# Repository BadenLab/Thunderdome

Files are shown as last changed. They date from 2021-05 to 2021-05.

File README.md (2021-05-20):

<p align="right">
<h1 align="center">Zebrafish Thunderdome</h1></p>
<h3 align="center">An open source and versatile spatio-chromatic stimulation system for behavioural experiments</h4>
<p align="center"><h6 align="right">by M.J.Y. Zimmermann, A.M. Chagas, G. Kafetzis & T. Baden</h6></p>

<br>

This project is licensed under the [GNU General Public License v3.0](https://github.com/BadenLab/LED-Zappelin/blob/master/LICENSE)<br>
The hardware is licensed under the [CERN OHL v1.2](https://github.com/BadenLab/LED-Zappelin/blob/master/PCB/LICENSE)

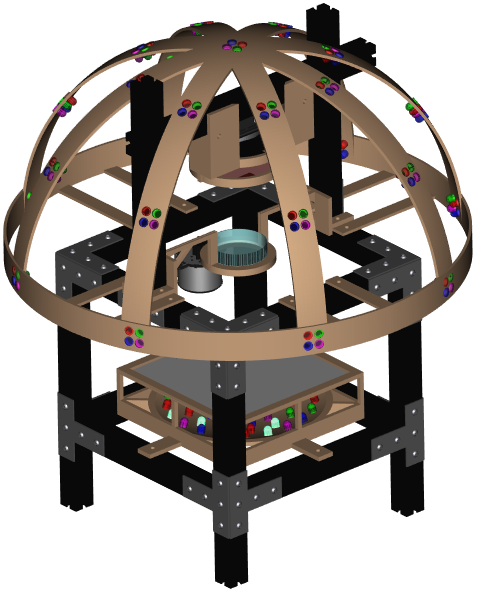
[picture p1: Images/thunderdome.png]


***

<h4 align="justify"> This project aims to investigate the larval zebrafish behavioural responses to spatio-chromatic stimulation in a free-swimming environment. The "Thunderdome"© is a stimulation system designed to experiment on the tetra-chromatic larval zebrafish. It is therefore designed around 4 set of LEDs (each LED matching the zebrafish' opsins peak absorption <a href="https://github.com/MaxZimmer/Zebra-Thunderdome/blob/main/References/Zimmermann%202018.pdf">Zimmermann et al. 2018</a> & <a href="https://github.com/MaxZimmer/Zebra-Thunderdome/blob/main/References/Zimmermann%202020.pdf">Zimmermann et al. 2020</a>, organised in 8 cardinal directions and 4 azimuths. Using machine-learning algorithms, fish motor responses (body direction, eyes orientation, tail kinetics, etc.) are identified and compared to well-known behavioural catalogs <a href="">ref</a> . The purpose of this project is to identify behavioural responses to specific spatio-chromatic stimulation which were/are studied in early visual system under two photon microscopy <a href="">ref,ref,ref</a></h4>

***

- [An open and versatile LED controler](#Introduction)
- [A semi-automated behavioural tracking](#Behaviour-tracking)
- [A detailed assembly and instruction manual](https://github.com/BadenLab/LED-Zappelin/blob/master/)
- [Required software](#Required_software)
- [Repository Structure](#Repository-Structure)

***

## Introduction

bonsai

***
## Behaviour tracking

<p align="justify">
For tracking the larval zebrafish movements, we are considering two different approaches:

- <a href="https://github.com/DeepLabCut/DeepLabCut">DeepLabCut</a>, a toolbox for markerless pose estimation based on transfer learning with deep neural networks that achieves excellent results with minimal training data <a href="https://github.com/MaxZimmer/Zebra-Thunderdome/blob/main/References/Mathis%202018.pdf">Mathis et al. 2018</a>, <a href="https://github.com/MaxZimmer/Zebra-Thunderdome/blob/main/References/Nath&Mathis%202019.pdf">Nath & Mathis 2019</a>.

- <a href="https://github.com/ncguilbeault/BonZeb">BonZeb</a>, a Bonsai library for high-resolution zebrafish behavioural tracking and analysis <a href="https://github.com/MaxZimmer/Zebra-Thunderdome/blob/main/References/Guilbeault%202019.pdf">Guilbeault 2019</a>  
</p>

***

## Required software

***

## Repository structure

```
├───3D Designs                                Contains printed parts for the stimulator
|   ├───FreeCad renderings                      - Printing files
|   ├───STL files                               - Printing files
|   └───SCAD files                              - SCAD files to be modified if need be
|
├───Arduino Code                              Stimulator Code
|   ├───Stimulator Code                       - Adaptable C+ code for running the stimulator
|   └───LED driver library                     - Library to run the TLC 5947
|
├───Bill of Materials                         List of necessary components and retailer suggestions
|
├───Bonsai code                               Bonsai pipeline for running the stimulation and export data
|
├───Datasheets                                - Contains all technical sheet for:
|   ├───Stimulator                            - ...micro-controller and LED driver
|   └───Spectrometer                          - ...device used for calibration
|
├───Images                                    Image repository
|
├───Instruction Manual                        Detailed manual to assemble and calibrate the stimulator
|   └───Stimulator Calibration                - Contains calibration recordings and the adaptable jupyter notebook script to calibrate the stimulator
|
├───PCB                                       KiCad and Gerber files to modify and generate PCB
|
└───References                                Publication used to design and conceive this model

```

***

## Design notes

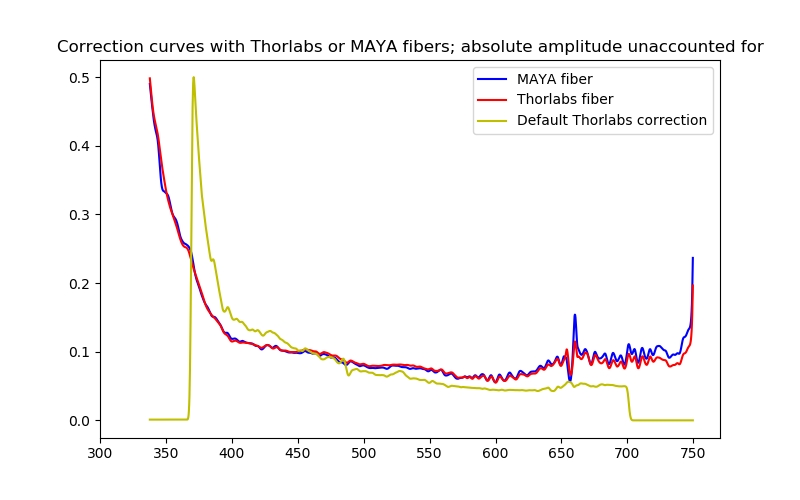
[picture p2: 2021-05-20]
Instruction Manual/Stimulator Calibration/Spectrometer_Recording/Spectrometer Correction Curves/Correction_curves.png

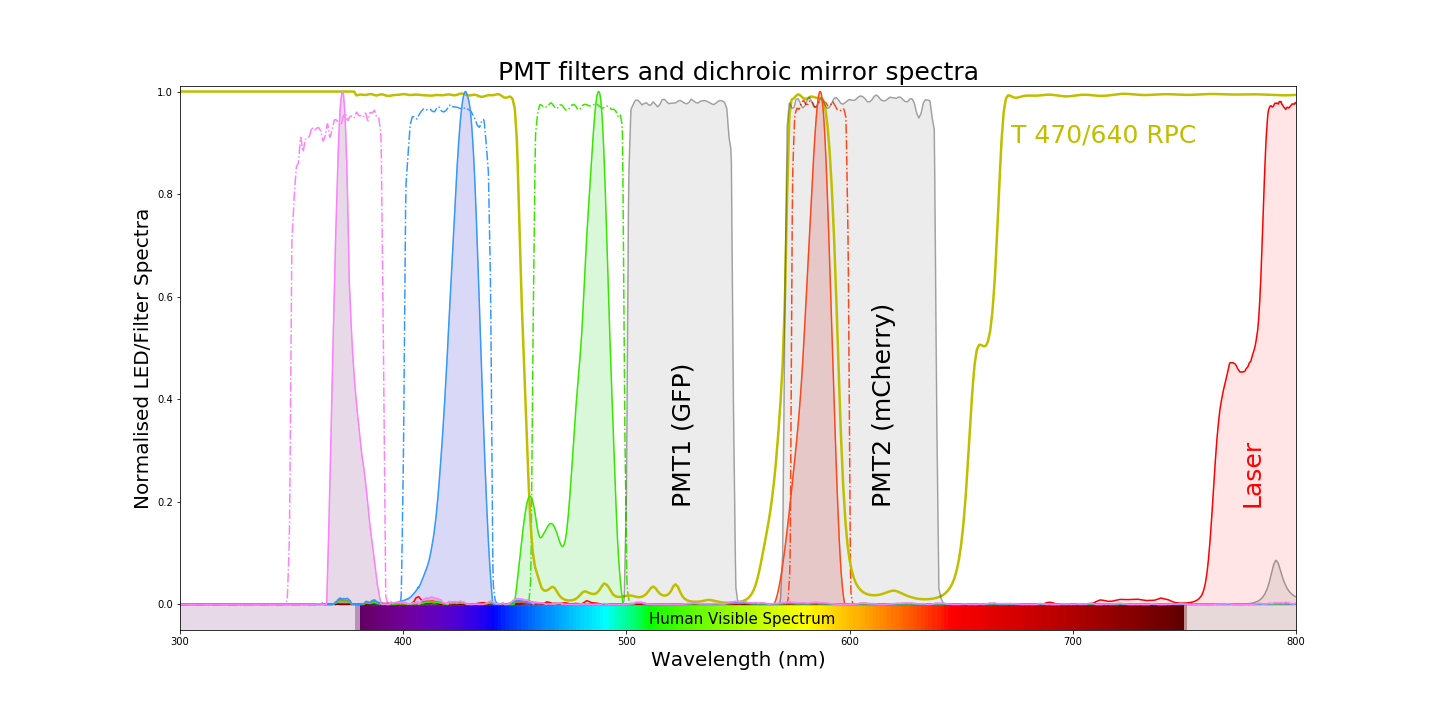
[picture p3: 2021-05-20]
Instruction Manual/Stimulator Calibration/Calibration_Figures/LED-PMT_Spectra.png

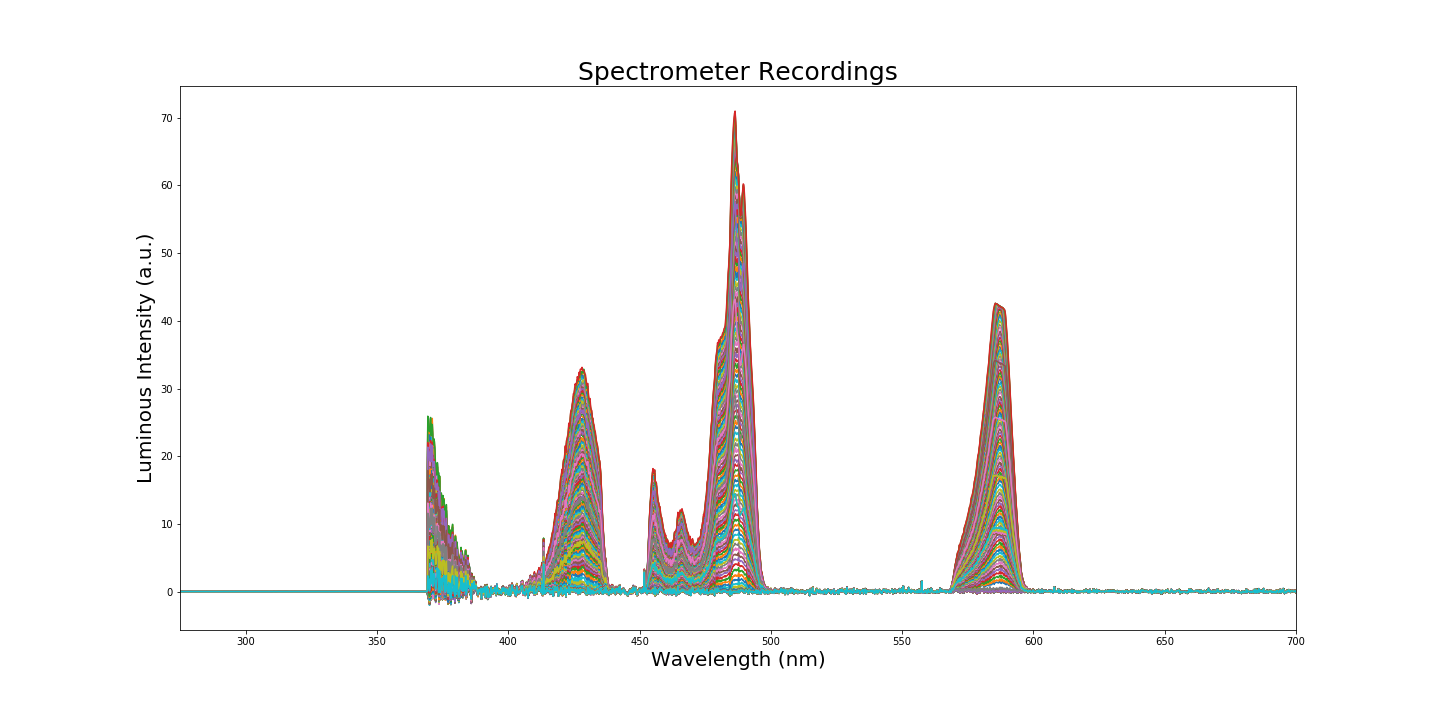
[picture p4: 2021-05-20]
Instruction Manual/Stimulator Calibration/Calibration_Figures/Spectrometer Recordings.png

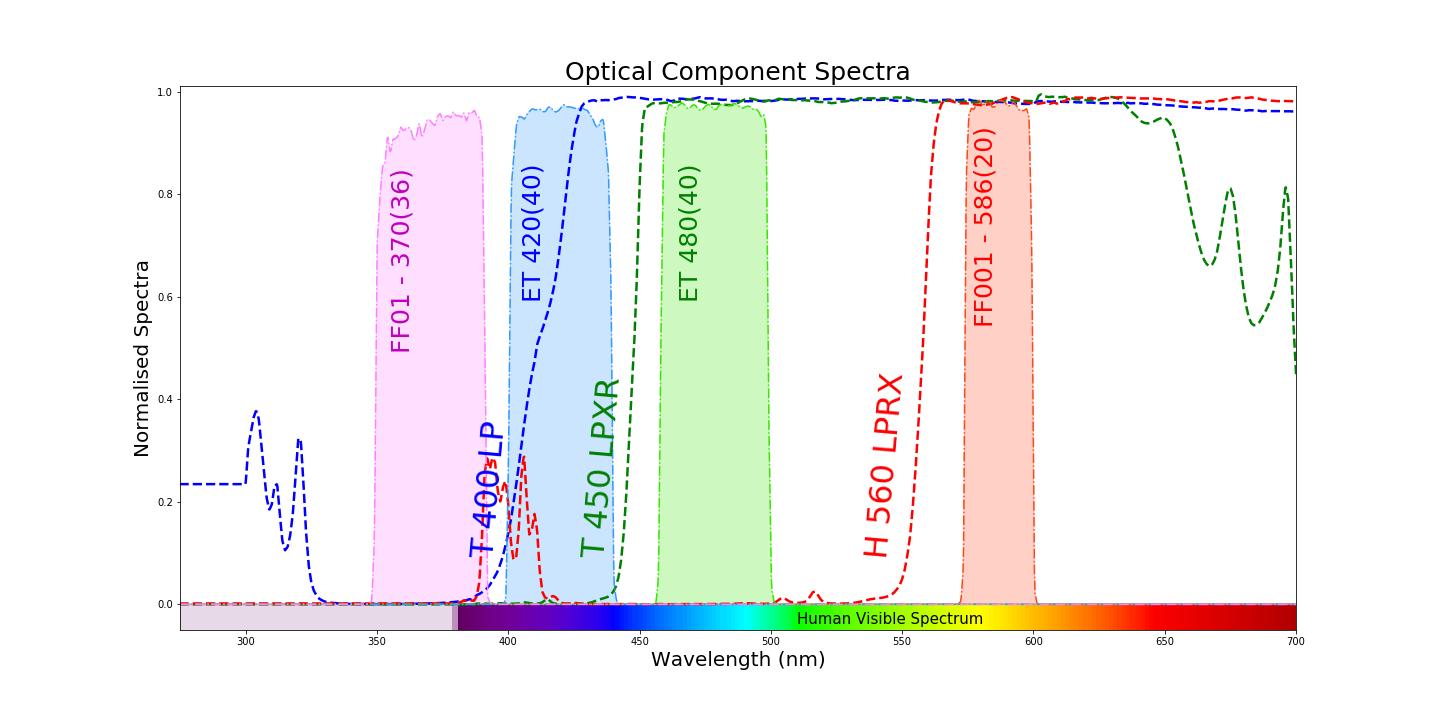
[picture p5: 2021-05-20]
Instruction Manual/Stimulator Calibration/Calibration_Figures/Optics_Spectra.png

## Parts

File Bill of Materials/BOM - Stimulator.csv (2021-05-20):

Name | Manufacturer | Order ID | Retailer | Quantity | Observation 1 | Observation 2 | Suggested URL | Cost
Adafruit Huzzah32 - ESP32 Feather | Adafruit | 3405 | Adafruit | 1 | Development Board | Easier to order it with header pins soldered | https://www.adafruit.com/product/3405 | £17
Adafruit TLC5947 | Adafruit | 1429 | Adafruit | 1 | LED Driver |  | https://www.adafruit.com/product/1429 | £12
BNC coaxial connectors | TE Connectivity | 1-1337542-0 | Farnell | 2 | Electronics | Right angle jacks, 50ohm | https://uk.farnell.com/greenpar-te-connectivity/1-1337542-0/rf-coaxial-bnc-right-angle-jack/dp/1020954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 | £3.70
2 way JST Female Connector Housing | RS Online | 820-1611 | JST | 8 | Electronics |  | https://uk.rs-online.com/web/p/pcb-connector-housings/8201611/ | £3.80
3 way JST Female Connector Housing | RS Online | 820-1614 | JST | 1 | Electronics |  | https://uk.rs-online.com/web/p/pcb-connector-housings/8201614/ | £1.90
4 way JST Female Connector Housing | RS Online | 820-1618 | JST | 2 | Electronics |  | https://uk.rs-online.com/web/p/pcb-connector-housings/8201618/ | £1.90
2 way JST PCB header | RS Online | 820-1554 | JST | 8 | Electronics |  | https://uk.rs-online.com/web/p/pcb-headers/8201554/ | £3.80
3 way JST PCB header | RS Online | 820-1557 | JST | 1 | Electronics |  | https://uk.rs-online.com/web/p/pcb-headers/8201557/ | £1.90
4 way JST PCB header | RS Online | 820-1551 | JST | 2 | Electronics |  | https://uk.rs-online.com/web/p/pcb-headers/8201551/ | £1.90
JST Crimp Connector Wire | RS Online | 01SHXSXH-26L 150 | RS | 15 | Electronics |  | https://uk.rs-online.com/web/p/products/8201548/ | £10.00
3 mm LED | Digikey | 350-1557-ND | Digikey | 4 | Electronics | 3mm round, tht | https://www.digikey.com/product-detail/en/dialight/5219210F/350-1557-ND/808955 | £2
Mount for 3 mm LED | Digikey | 67-1330-ND | Digikey | 4 | Electronics | 3mm panel mount | https://www.digikey.com/products/en?keywords=67-1330-ND | £1
Mount for 5 mm LED | Digikey | 67-1332-ND | Digikey | 4 | Electronics | 5mm panel mount | https://www.digikey.com/product-detail/en/lumex-opto-components-inc/SSH-LX5091/67-1332-ND/144810 | £1
Rocker LED switch |  |  | Ebay | 1 | Electronics | Round Switch / 3 pins | https://www.ebay.co.uk/p/Blue-On-off-Lighted-LED-Round-Rocker-Switch-Car-Dashboard-Dash-SPST-12v/1942302409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 | £2.50
220 Ohms Resitor | RS Online | 707-7612 | RS | 1 | Electronics | Through hole | https://uk.rs-online.com/web/p/through-hole-fixed-resistors/7077612/ | £1.16
470 Ohms Resitor | RS Online | 707-7647 | RS | 1 | Electronics | Through hole | https://uk.rs-online.com/web/p/through-hole-fixed-resistors/7077647/ | £1.16
10 kOhms Trimmer Potentiometer | TT Electronics | 89PR10KLF | Farnell | 4 | Electronics | Through Hole | https://uk.farnell.com/bi-technologies-tt-electronics/89pr10klf/trimmer-resistor/dp/1653213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 | £5.95
PCB socket | Samtec | SSW-116-02-G-S | RS | 6 | Electronics | 1 row, 15 pin | https://uk.rs-online.com/web/p/pcb-sockets/7655795/ | £3
2.1 mm right angle DC socket | RS Online | 884-0957 | RS | 1 | Electronics | 2.1 mm right angle | https://uk.rs-online.com/web/p/dc-power-sockets/8840957/ | £1
distinc colour wires | RS Online | 331-862 | RS | 100 cm | Electronics | 20 AWG | https://uk.rs-online.com/web/p/hookup-equipment-wire/0331862/ | £5
Cable shrink | RS Online | 170-6377 | RS | 20 cm | Electronics | Shrunk diameter 1.2 mm | https://uk.rs-online.com/web/p/heat-shrink-cold-shrink-sleeves/1706377/ | £1.58
M3 x 10mm screw | RS Online | 660-4636 | RS | 4 | Mechanical | M3 x 10 Hex socket cap | https://uk.rs-online.com/web/p/socket-screws/6604636/ | £4
M3 nut | RS Online | 122-4400 | RS | 4 | Mechanical | M3 nuts | https://uk.rs-online.com/web/p/hex-nuts/1224400/ | £4
M4 x 50mm Hex Socket Cap Screws | RS Online | 304-4592 | RS | 4 | Mechanical | M4 x 50 | https://uk.rs-online.com/web/p/socket-screws/3044592/ | £4
M4 nut | RS Online | 189-579 | RS | 4 | Mechanical | M4 nuts | https://uk.rs-online.com/web/p/hex-nuts/0189579/ | £4
 |  |  |  |  |  |  |  | £101

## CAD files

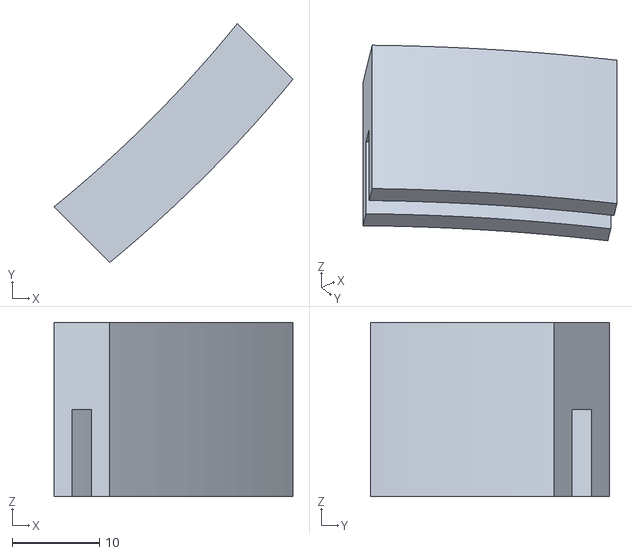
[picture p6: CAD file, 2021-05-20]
3D design/STL files/Dome_links.stl
27.5 x 27.5 x 20.0

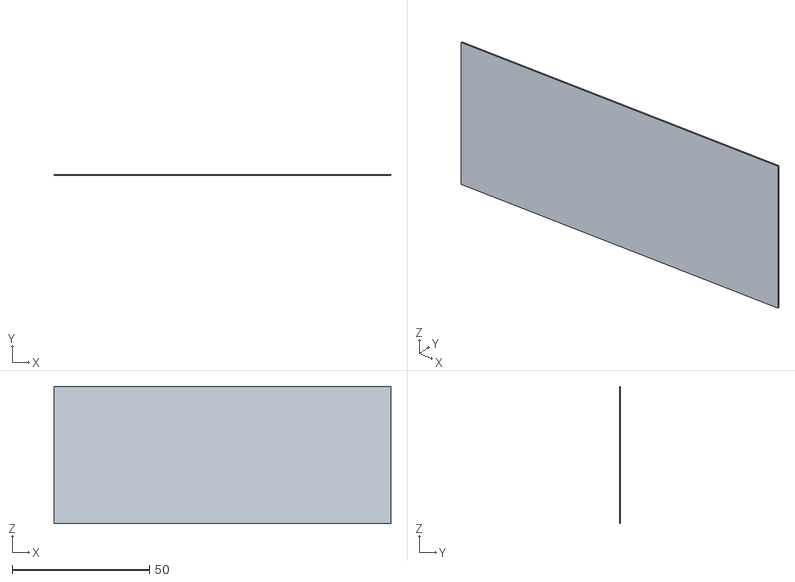
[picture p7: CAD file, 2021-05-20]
3D design/STL files/Dish_Separator.stl
122.8 x 0.5 x 50.0

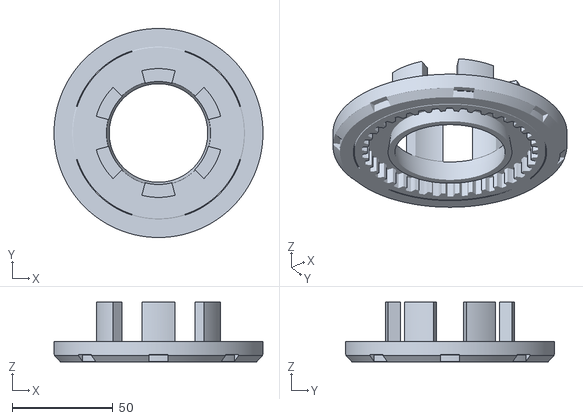
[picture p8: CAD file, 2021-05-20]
3D design/STL files/OKR_6.stl
103.5 x 103.5 x 29.5

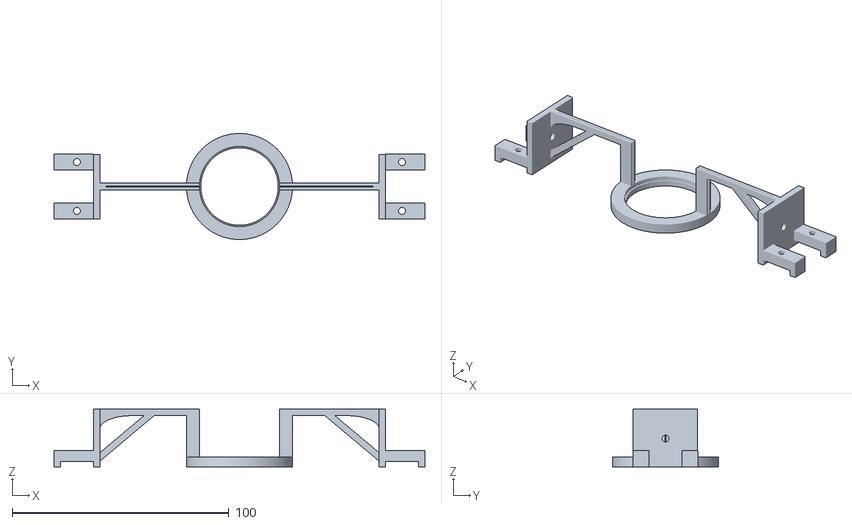
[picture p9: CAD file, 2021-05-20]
3D design/STL files/Dish_Holder.stl
171.2 x 49.0 x 26.7

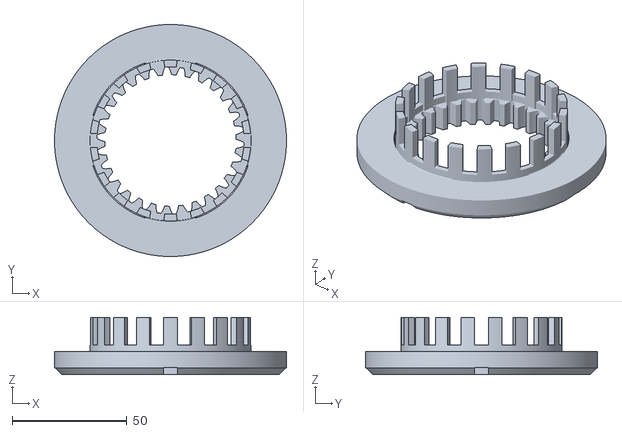
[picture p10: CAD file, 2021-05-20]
3D design/STL files/OKR_18.stl
101.0 x 101.0 x 25.0

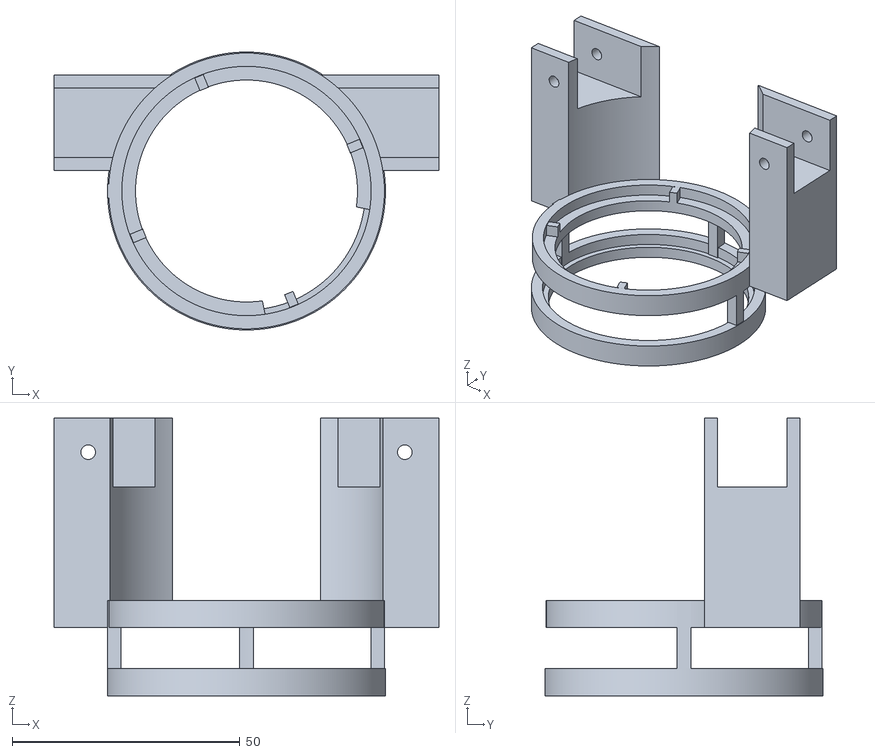
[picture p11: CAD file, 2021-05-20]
3D design/STL files/Camera_Holder.stl
84.5 x 61.0 x 61.0

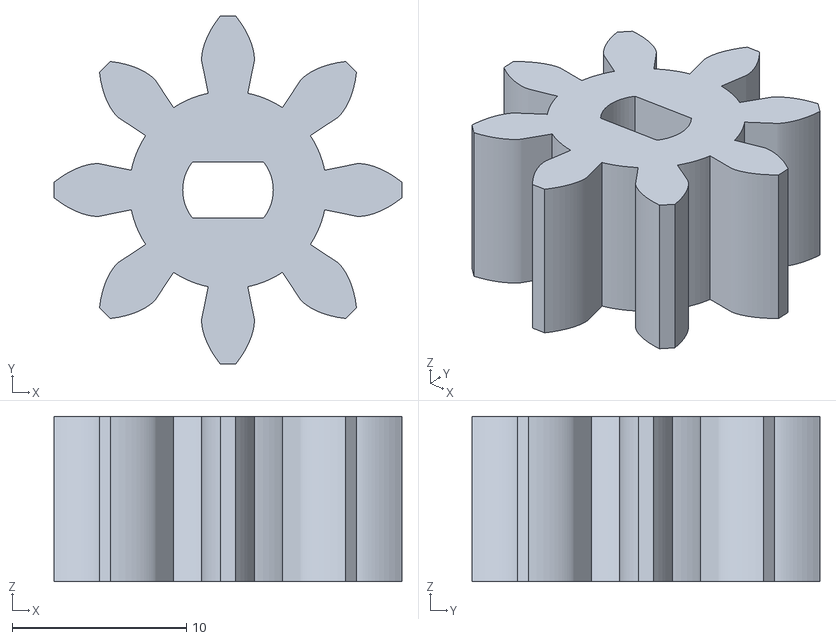
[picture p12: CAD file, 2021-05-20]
3D design/STL files/OKR_ GearBevel.stl
20.0 x 20.0 x 9.50

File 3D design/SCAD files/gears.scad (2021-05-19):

$fn = 100;


/* [Basic Gear Parameters] */
Module = 1; // 0.01

Gear_type = "bevel_gears"; // ["rack":Rack, "spur_gear":Spur gear, "herringbone_gear":Herringbone gear, "rack_and_pinion": Rack and pinion, "annular_spur_gear":Annular/Internal spur gear, "annular_herringbone_gear":Annular/Internal herrinbone gear, "planetary_gear":Planetary gear, "bevel_gear":Bevel gear, "bevel_gears":Bevel gears, "herringbone_bevel_gear":Herringbone bevel gear, "herringbone_bevel_gears":Herringbone bevel gears, "worm":Worm, "worm_drive":Worm drive]

width = 5.0; // 0.01
teeth = 30;
bore = 3; // 0.01
straight = false;

/* [Advanced Parameters] */
hub = true;
hub_diameter = 6; // 0.01
hub_thickness = 5; // 0.01
// (Weight optimization if applicable)
optimized = false;
pressure_angle = 20; // 0.01
helix_angle = 20; // 0.01
clearance = 0.05; // 0.01

/* [Multi-gear configurations] */
idler_teeth = 36;
idler_bore = 3; // 0.01
assembled = true;

/* [Rack parameters] */
rack_length = 50; // 0.01
rack_height = 4; // 0.01

/* [Worm parameters] */
// Worm lead angle                                                                (For final worm diameter, see also number of starts.)
lead_angle = 4; // 0.01
// Number of starts                                                                (For final worm diameter, see also lead angle.)
worm_starts = 1;
// Worm bore                                             (Please note: The bore in Basic Gear Parameters is used for the bore of the worm gear, not the worm.)
worm_bore = 3; // 0.01
worm_length = 6; // 0.01

/* [Bevel gear parameters] */
bevel_angle = 45; // 0.01
bevel_width = 5; // 0.01
shaft_angle = 90; // 0.01

/* [Annular/internal gear parameters] */
rim_width = 3; // 0.01

/* [Planetary gear parameters] */
solar_teeth = 20;
planet_teeth = 10;
number_of_planets = 3;


module customizer_separator() {}

finalHelixAngle = straight ? 0 : helix_angle;
final_hub_diameter = hub ? hub_diameter : 0;
final_hub_thickness = hub ? hub_thickness : 0;



/* Bibliothek für Evolventen-Zahnräder, Schnecken und Zahnstangen

Enthält die Module
- zahnstange(modul, laenge, hoehe, breite, eingriffswinkel=20, schraegungswinkel=0)
- stirnrad(modul, zahnzahl, breite, bohrung, eingriffswinkel=20, schraegungswinkel=0, optimiert=true)
- pfeilrad(modul, zahnzahl, breite, bohrung, eingriffswinkel=20, schraegungswinkel=0, optimiert=true)
- zahnstange_und_rad (modul, laenge_stange, zahnzahl_rad, hoehe_stange, bohrung_rad, breite, eingriffswinkel=20, schraegungswinkel=0, zusammen_gebaut=true, optimiert=true)
- hohlrad(modul, zahnzahl, breite, randbreite, eingriffswinkel=20, schraegungswinkel=0)
- pfeilhohlrad(modul, zahnzahl, breite, randbreite, eingriffswinkel=20, schraegungswinkel=0)
- planetengetriebe(modul, zahnzahl_sonne, zahnzahl_planet, anzahl_planeten, breite, randbreite, bohrung, eingriffswinkel=20, schraegungswinkel=0, zusammen_gebaut=true, optimiert=true)
- kegelrad(modul, zahnzahl,  teilkegelwinkel, zahnbreite, bohrung, eingriffswinkel=20, schraegungswinkel=0)
- pfeilkegelrad(modul, zahnzahl, teilkegelwinkel, zahnbreite, bohrung, eingriffswinkel=20, schraegungswinkel=0)
- kegelradpaar(modul, zahnzahl_rad, zahnzahl_ritzel, achsenwinkel=90, zahnbreite, bohrung, eingriffswinkel = 20, schraegungswinkel=0, zusammen_gebaut=true)
- pfeilkegelradpaar(modul, zahnzahl_rad, zahnzsahl_ritzel, achsenwinkel=90, zahnbreite, bohrung, eingriffswinkel = 20, schraegungswinkel=0, zusammen_gebaut=true)
- schnecke(modul, gangzahl, laenge, bohrung, eingriffswinkel=20, steigungswinkel=10, zusammen_gebaut=true)
- schneckenradsatz(modul, zahnzahl, gangzahl, breite, laenge, bohrung_schnecke, bohrung_rad, eingriffswinkel=20, steigungswinkel=0, optimiert=true, zusammen_gebaut=true)

Beispiele für jedes Modul befinden sich auskommentiert am Ende dieser Datei

Autor:		Dr Jörg Janssen
Stand:		29. Oktober 2018
Version:	2.3
Lizenz:		Creative Commons - Attribution, Non Commercial, Share Alike

Erlaubte Module nach DIN 780:
0.05 0.06 0.08 0.10 0.12 0.16
0.20 0.25 0.3  0.4  0.5  0.6
0.7  0.8  0.9  1    1.25 1.5
2    2.5  3    4    5    6
8    10   12   16   20   25
32   40   50   60

*/


// Allgemeine Variablen
pi = 3.14159;
rad = 57.29578;
spiel = clearance;	// Spiel zwischen Zähnen

/*	Wandelt Radian in Grad um */
function grad(eingriffswinkel) = eingriffswinkel*rad;

/*	Wandelt Grad in Radian um */
function radian(eingriffswinkel) = eingriffswinkel/rad;

/*	Wandelt 2D-Polarkoordinaten in kartesische um
    Format: radius, phi; phi = Winkel zur x-Achse auf xy-Ebene */
function pol_zu_kart(polvect) = [
	polvect[0]*cos(polvect[1]),  
	polvect[0]*sin(polvect[1])
];

/*	Kreisevolventen-Funktion:
    Gibt die Polarkoordinaten einer Kreisevolvente aus
    r = Radius des Grundkreises
    rho = Abrollwinkel in Grad */
function ev(r,rho) = [
	r/cos(rho),
	grad(tan(rho)-radian(rho))
];

/*  Kugelevolventen-Funktion
    Gibt den Azimutwinkel einer Kugelevolvente aus
    theta0 = Polarwinkel des Kegels, an dessen Schnittkante zur Großkugel die Evolvente abrollt
    theta = Polarwinkel, für den der Azimutwinkel der Evolvente berechnet werden soll */
function kugelev(theta0,theta) = 1/sin(theta0)*acos(cos(theta)/cos(theta0))-acos(tan(theta0)/tan(theta));

/*  Wandelt Kugelkoordinaten in kartesische um
    Format: radius, theta, phi; theta = Winkel zu z-Achse, phi = Winkel zur x-Achse auf xy-Ebene */
function kugel_zu_kart(vect) = [
	vect[0]*sin(vect[1])*cos(vect[2]),  
	vect[0]*sin(vect[1])*sin(vect[2]),
	vect[0]*cos(vect[1])
];

/*	prüft, ob eine Zahl gerade ist
	= 1, wenn ja
	= 0, wenn die Zahl nicht gerade ist */
function istgerade(zahl) =
	(zahl == floor(zahl/2)*2) ? 1 : 0;

/*	größter gemeinsamer Teiler
	nach Euklidischem Algorithmus.
	Sortierung: a muss größer als b sein */
function ggt(a,b) = 
	a%b == 0 ? b : ggt(b,a%b);

/*	Polarfunktion mit polarwinkel und zwei variablen */
function spirale(a, r0, phi) =
	a*phi + r0; 

/*	Kopiert und dreht einen Körper */
module kopiere(vect, zahl, abstand, winkel){
	for(i = [0:zahl-1]){
		translate(v=vect*abstand*i)
			rotate(a=i*winkel, v = [0,0,1])
				children(0);
	}
}

/*  Zahnstange
    modul = Höhe des Zahnkopfes über der Wälzgeraden
    laenge = Länge der Zahnstange
    hoehe = Höhe der Zahnstange bis zur Wälzgeraden
    breite = Breite eines Zahns
    eingriffswinkel = Eingriffswinkel, Standardwert = 20° gemäß DIN 867. Sollte nicht größer als 45° sein.
    schraegungswinkel = Schrägungswinkel zur Zahnstangen-Querachse; 0° = Geradverzahnung */
module zahnstange(modul, laenge, hoehe, breite, eingriffswinkel = 20, schraegungswinkel = 0) {

	// Dimensions-Berechnungen
	modul=modul*(1-spiel);
	c = modul / 6;												// Kopfspiel
	mx = modul/cos(schraegungswinkel);							// Durch Schrägungswinkel verzerrtes modul in x-Richtung
	a = 2*mx*tan(eingriffswinkel)+c*tan(eingriffswinkel);		// Flankenbreite
	b = pi*mx/2-2*mx*tan(eingriffswinkel);						// Kopfbreite
	x = breite*tan(schraegungswinkel);							// Verschiebung der Oberseite in x-Richtung durch Schrägungswinkel
	nz = ceil((laenge+abs(2*x))/(pi*mx));						// Anzahl der Zähne
	
	translate([-pi*mx*(nz-1)/2-a-b/2,-modul,0]){
		intersection(){											// Erzeugt ein Prisma, das in eine Quadergeometrie eingepasst wird
			kopiere([1,0,0], nz, pi*mx, 0){
				polyhedron(
					points=[[0,-c,0], [a,2*modul,0], [a+b,2*modul,0], [2*a+b,-c,0], [pi*mx,-c,0], [pi*mx,modul-hoehe,0], [0,modul-hoehe,0],	// Unterseite
						[0+x,-c,breite], [a+x,2*modul,breite], [a+b+x,2*modul,breite], [2*a+b+x,-c,breite], [pi*mx+x,-c,breite], [pi*mx+x,modul-hoehe,breite], [0+x,modul-hoehe,breite]],	// Oberseite
					faces=[[6,5,4,3,2,1,0],						// Unterseite
						[1,8,7,0],
						[9,8,1,2],
						[10,9,2,3],
						[11,10,3,4],
						[12,11,4,5],
						[13,12,5,6],
						[7,13,6,0],
						[7,8,9,10,11,12,13],					// Oberseite
					]
				);
			};
			translate([abs(x),-hoehe+modul-0.5,-0.5]){
				cube([laenge,hoehe+modul+1,breite+1]);			// Quader, der das Volumen der Zahnstange umfasst
			}	
		};
	};	
}

/*  Stirnrad
    modul = Höhe des Zahnkopfes über dem Teilkreis
    zahnzahl = Anzahl der Radzähne
    breite = Zahnbreite
    bohrung = Durchmesser der Mittelbohrung
    eingriffswinkel = Eingriffswinkel, Standardwert = 20° gemäß DIN 867. Sollte nicht größer als 45° sein.
    schraegungswinkel = Schrägungswinkel zur Rotationsachse; 0° = Geradverzahnung
	optimiert = Löcher zur Material-/Gewichtsersparnis bzw. Oberflächenvergößerung erzeugen, wenn Geometrie erlaubt */
module stirnrad(modul, zahnzahl, breite, bohrung, nabendicke=0, nabendurchmesser=0, eingriffswinkel = 20, schraegungswinkel = 0, optimiert = true) {
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

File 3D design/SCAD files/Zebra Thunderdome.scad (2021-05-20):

// // // // // // // // // // // // // // // // // // // // // // // // // // // //
/*                               General Parameters                              */
// // // // // // // // // // // // // // // // // // // // // // // // // // // //

Walls = 3;
tol = 0.1;
Tol = 0.75;
TOL = 0.5; // for OKR
Smoothness = 360;

// // // // // // // // // // // // // // // // // // // // // // // // // // // //
/*                                    Switches                                   */
// // // // // // // // // // // // // // // // // // // // // // // // // // // //

Frames = 10;
Links = 10;
Petri_Dish = 10;
Dish_Holder = 20;
Dome = 10;
OKR = 10;
Gear = 10;
Gear_Bevel = 20;
Cut = 10;
Platform = 10;
IR_LED = 10;
Camera = 10;
IR_Ring = 10;
IR_Filter = 10;
IR_Illumination = 10;
Separator = 10;
Platform_Rods = 10;


LED = 10;
LED_Holder = 10;
    Red_LED = 20;
    Green_LED = 20;
    Blue_LED = 20;
    UV_LED = 20;
Rods = 10;
Stepper = 10;
Platform_Steppers = 10;

movement =10;
z_plat = -40+40;
coupe1 = 10;
coupe2 = 10;
// // // // // // // // // // // // // // // // // // // // // // // // // // // //
/*                                Module Parameters                              */
// // // // // // // // // // // // // // // // // // // // // // // // // // // //


// // // // // General  // // // // // //
    r_Dome = 150;
    camera_height = 110;
    M3 = 1.5+tol;
    M4 = 2+tol;
    M6 = 3+tol;
x_Attache = 10;
h_Attache = 5;
h_Base = 20;
WidthArm = 25;

    
// // // // // LED  // // // // // //
    
Steps = 45;
End = 315;
rr = r_Dome;
r_LED = 5.75/2 + tol;
h_LEDHolder = 1.5;
r_LEDHolder = 10;
h_LED = 20;
LED1 = rr/5;
LED2 = rr*3/5;  

sp = 0.55+0.1;
zzz = 2.5;
R_LEDholder = 7.75/2;
r_LEDholder = 5/2;
h_LEDholder = 0.5+zzz;
z_LEDholder = 4.6-zzz;

R_LED = 5/2+tol;
H_LED = 8.5;
R_Rim = 5.9/2+tol;
H_Rim = 1.15;
R_pin = 0.5;
H_pin = 10;
h_pin = 7.5;

R_IR = 6/2;
r_IR = 5/2+tol;
H_IR = 1;
h_IR = 7;

connection = 4;

// // // // // Petri Dish  // // // // // //
    r_Dish = 36.75/2;//37.5/2;
    r_Dish2 = 36.75/2;//53.5/2;
    h_Dish = 10;
    h_Dish2 = 10;
    w_Dish =0.5;
    
    r_DishHolder = r_Dish+tol+Walls+r_IR+Walls;
    r_DishHolder2 = r_Dish2+tol+Walls+Walls;
    
// // // // // OKR  // // // // // //
    r_OKR = r_DishHolder+H_IR+Walls+connection+TOL;
    h_OKR = 3/2*h_Dish;
    n_OKR = 12/2;
    p_OKR = PI * r_OKR ;
    Slice = p_OKR / n_OKR ;

// // // // // Gear  // // // // // //
    Module = 2; // 0.01
    width = 10.0; // 0.01 //rim height
    rim_width = 2.65; 
    teeth = 30;
    pressure_angle = 20; // 0.01
    helix_angle = 20-10; // 0.01
    clearance = 0.05; //  Play between teeth

// // // // // Aluminium frames  // // // // // //
    Alu1 = 50;
    Alu2 = 100;
    Alu3 = 150;
    Alu4 = 200;
    Alu5 = 300;
    x_Alu = 15;
    g_Alu = 3;
    h_Alu = 5;
    d_Alu = 1;
    x_Eq = 44;
    y_Eq = 15;
    z_Eq = 1;
    r_screw = 2.5;
    r_hex = 1.5;


// // // // // // // // // // // // // // // // // // // // // // // // // // // //
/*                                     Module                                    */
// // // // // // // // // // // // // // // // // // // // // // // // // // // //


// // // // // Dome  // // // // // //
module Sphere(){
difference(){
    union(){
        Dome_Base();
        intersection(){   
            sphere(r=rr,$fn=Smoothness);
            union(){
                for ( i = [0:Steps:End] ) {
                    rotate([0,0,i])translate([-WidthArm/2,0,0])cube([WidthArm,rr,rr]);
                }
            }
        }
    }
    sphere(r=rr-Walls,$fn=Smoothness);
    translate([-rr,-rr,-rr])cube([2*rr,2*rr,rr]);
    LEDs();
}
rotate([0,0,-45/2])Attaches();
}

module Sphere2(){
difference(){
    union(){
        Dome_Base();
        for ( i = [0:3] ){
            difference(){
                rotate([90,0,i*360/8])translate([0,0,-WidthArm/2])cylinder(r=rr,h=WidthArm,$fn=Smoothness);
                rotate([90,0,i*360/8])translate([0,0,-WidthArm/2-tol])cylinder(r=rr-Walls,h=WidthArm+2*tol,$fn=Smoothness);
            }
        }
    }
    translate([-rr,-rr,-rr])cube([2*rr,2*rr,rr]);
    LEDs();
}
rotate([0,0,-45/2])Attaches();
}

module Dome_Base(){
difference(){
    cylinder(r=rr,h=h_Base,$fn=Smoothness);
    translate([0,0,-tol])cylinder(r=rr-Walls,h=h_Base+2*tol,$fn=Smoothness);
}
}

module Attaches(){
difference(){
    intersection(){
        cylinder(r=rr,h=h_Attache,$fn=Smoothness);
        union(){
            translate([-x_Attache/2-2*x_Attache,-rr,0])cube([x_Attache,rr-Alu3/2+x_Alu/2,h_Attache]);
            translate([-x_Attache/2+2*x_Attache,-rr,0])cube([x_Attache,rr-Alu3/2+x_Alu/2,h_Attache]);
            translate([-x_Attache/2-2*x_Attache,Alu3/2-x_Alu/2,0])cube([x_Attache,rr-Alu3/2+x_Alu/2,h_Attache]);
            translate([-x_Attache/2+2*x_Attache,Alu3/2-x_Alu/2,0])cube([x_Attache,rr-Alu3/2+x_Alu/2,h_Attache]);
            translate([-rr,-x_Attache/2-2*x_Attache,0])cube([rr-Alu3/2+x_Alu/2,x_Attache,h_Attache]);
            translate([-rr,-x_Attache/2+2*x_Attache,0])cube([rr-Alu3/2+x_Alu/2,x_Attache,h_Attache]);
            translate([Alu3/2-x_Alu/2,-x_Attache/2-2*x_Attache,0])cube([rr-Alu3/2+x_Alu/2,x_Attache,h_Attache]);
            translate([Alu3/2-x_Alu/2,-x_Attache/2+2*x_Attache,0])cube([rr-Alu3/2+x_Alu/2,x_Attache,h_Attache]);
        }
    }
    translate([-2*x_Attache,Alu3/2,0])cylinder(r=M3,h=h_Attache,$fn=60);
    translate([2*x_Attache,Alu3/2,0])cylinder(r=M3,h=h_Attache,$fn=60);
    translate([-2*x_Attache,-Alu3/2,0])cylinder(r=M3,h=h_Attache,$fn=60);
    translate([2*x_Attache,-Alu3/2,0])cylinder(r=M3,h=h_Attache,$fn=60);
    translate([Alu3/2,-2*x_Attache,0])cylinder(r=M3,h=h_Attache,$fn=60);
    translate([Alu3/2,2*x_Attache,0])cylinder(r=M3,h=h_Attache,$fn=60);
    translate([-Alu3/2,-2*x_Attache,0])cylinder(r=M3,h=h_Attache,$fn=60);
    translate([-Alu3/2,2*x_Attache,0])cylinder(r=M3,h=h_Attache,$fn=60);
}
}

module LED_Holes(){
rotate([5+sp,1+sp,1])cylinder(r=r_LED,h=rr+10,$fn=60);
rotate([5+sp,-1-sp,-1])cylinder(r=r_LED,h=rr+10,$fn=60);
rotate([3-sp,1+sp,1])cylinder(r=r_LED,h=rr+10,$fn=60);
rotate([3-sp,-1-sp,-1])cylinder(r=r_LED,h=rr+10,$fn=60);

}
module LEDs(){
for ( i = [0:Steps:End] ){
    for ( j = [90:-30:30] ){
        rotate([-j,0,i])translate([0,0,0])LED_Holes();
        rotate([-j+4,0,i])translate([0,0,rr-h_LEDHolder])cylinder(r=r_LEDHolder,h=h_LEDHolder,$fn=Smoothness);
    }
}
}

if (Dome == 1){
    rotate([0,0,45/2])Sphere();
}
if (Dome == 2){
    difference(){
        intersection(){
            rotate([0,0,45/2])Sphere2();
            rotate([0,0,-45])cube([200,200,200]);
        }
        cut();
    }
}
// // // // // Dome link // // // // // //
module cut(){
intersection(){
    cylinder(r=rr,h=h_Base,$fn=Smoothness);
    union(){
        mirror([0,1,0])translate([0,0,h_Base/2])rotate([0,0,-45])cube([rr+Walls,5*Walls,h_Base/2]);
        translate([0,0,h_Base/2])rotate([0,0,-45])cube([rr+Walls,5*Walls,h_Base/2]);
    }
}
}

module cut_posi(){
difference(){
    intersection(){
        difference(){
            cylinder(r=rr+Walls,h=h_Base,$fn=Smoothness);
            cylinder(r=rr-2*Walls,h=h_Base,$fn=Smoothness);
            
        }
        union(){
            mirror([0,1,0])rotate([0,0,0])cube([rr+2*Walls,5*Walls-tol,h_Base]);
            rotate([0,0,0])cube([rr+2*Walls,5*Walls-tol,h_Base]);
        }
    }
    intersection(){
        difference(){
            cylinder(r=rr+tol,h=h_Base/2,$fn=Smoothness);
            cylinder(r=rr-Walls-tol,h=h_Base/2,$fn=Smoothness);
            
        }
        union(){
            mirror([0,1,0])rotate([0,0,0])cube([rr+2*Walls,5*Walls,h_Base/2]);
            rotate([0,0,0])cube([rr+2*Walls,5*Walls,h_Base/2]);
        }
    }
}
}

if ( Cut ==1 ){ 
    rotate([0,0,-45])cut_posi();
}
    
// // // // // OKR // // // // // //
t_angle = 30;
t_x0 = 0;
t_y0 = 0;
t_x1 = r_OKR;
t_y1 = tan(t_angle/2) * t_x1;
t_x2 = r_OKR;
t_y2 = -tan(t_angle/2) * t_x1;
t_z = h_OKR+1.5*Walls+tol;
points =[ [t_x0,t_y0],[t_x1,t_y1],[t_x2,t_y2] ];
module Slices(){
difference(){
    cylinder(r=r_Dish+4.5*Walls,h=h_OKR+1.5*Walls,$fn=Smoothness);
    translate([0,0,-tol])cylinder(r=r_Dish+2.5*Walls-0.4,h=h_OKR+1.5*Walls+2*tol,$fn=Smoothness);

    translate([0,0,-tol])intersection(){
            cylinder(r=r_OKR,h=h_OKR+1.5*Walls+2*tol,$fn=Smoothness);
            for ( i = [0:((360/t_angle)-1)/2] ){
                //rotate([0,0,i*(360/n_OKR)])translate([0,-Slice/2,0])cube([r_OKR,Slice,h_OKR+1.5*Walls+tol]);
                rotate([0,0,(2*t_angle)*i])linear_extrude (height = t_z+2*tol)polygon(points);
        }
    }
}
}
module OKR(){
Slices();
translate([0,0,-Walls])difference(){
    cylinder(r=R_Gear,h=Walls,$fn=Smoothness);
    translate([0,0,-tol])cylinder(r=r_Dish+2.5*Walls,h=Walls+2*tol,$fn=Smoothness);
}
}
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

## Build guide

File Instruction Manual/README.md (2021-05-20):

<p align="right">
<h1 align="center">Instruction Manual</h1></p>

***

## Overview



<p align="justify">This document contains detailed assembly instructions, a software guideline to customize stimuli, and includes a parts list.</p>

 The Arduino code and 3D printing files (SCAD and STL) can be downloaded [here](https://github.com/BadenLab/LED-Zappelin/tree/master/3D%20Designs), and further modified to fit customise purposes. The aim of this device is to finely control LEDs used in combination with a 2-photon microscope.

The device consists of a custom-designed PCB, an [ESP32 development board](https://learn.adafruit.com/adafruit-huzzah32-esp32-feather) (or an Arduino Nano if the stimulator does not need to be combined with a 2 photon microscope), a [LED driver](https://learn.adafruit.com/tlc5947-tlc59711-pwm-led-driver-breakout/overview) and various off-the-shelf components.

***

- [Assembling the Stimulator](#Assembling-the-Stimulator)
- [Programming the Stimulator](#Programming-the-ESP32)
- [Operating the Stimulator](#Operating-the-Stimulator)
- [Calibrating the Stimulator](#Calibrating-the-Stimulator)

***

## Assembling the stimulator



<p align="center"><h4 align="left">1 – Obtaining the custom-designed PCB</h4></p>

From the GitHub repository, one can find the [gerber.zip folder](https://github.com/BadenLab/LED-Zappelin/tree/master/PCB/Stimulator) needed to order the PCB to any manufacturer company (i.e. https://jlcpcb.com).

Ordering a minimum of five units should not cost more than £10. Gerber files were designed with [KiCad 5.0](http://kicad-pcb.org/).

Schematics and PCB footprint can be downloaded and modified from the same repository if need be.

****

<p align="center"><h4 align="left">2 – Soldering the custom-designed PCB</h4></p>


<p align="justify">The board is self-explanatory. On the left, two options are available, one for the Arduino (close rows) the other for the ESP (spread rows). There is no need to solder more JST pins that the number of LED required for the desired stimulator.

<p align="justify">The jumper on the top (Signal Inverter) allows the inversion of the TTL "Blanking" signals. For ScanImage users, the jumper should be placed at the upper position.

<p align="justify">The jumper at the bottom of the board (Voltage Divider) allows to tune down the voltage from 5 to 3.3V if the ESP is used instead of an Arduino. ESP32 unlike Arduino Nano, works on a 3.3V logic; no higher tension should be sent to this board. Since most TTL deliver 5V pulses, we selected a 220/470Ω divider to bring a 5V blanking signal into a 3.3V input. Depending on the blanking signal generator used, this divider can be modified to fit one’s personal design or bypassed by only bridging the 220Ω resistor.

</br>
</br>



<p align="justify">The Adafruit TLC5947 LED driver is a constant current driver configured by default to set the current level at 15mA per channel, which is virtually safe for any LED. However, one can operate at different current by replacing the on-board reference resistor with a through hole resistor. The driver is capable to deliver up to 30mA, the graph below shows the relationship between resistance and output current. </p>

****

<p align="center"><h4 align="left">3 – Mounting the potentiometer</h4></p>


In order to finely adjust each LED power, we added multiple-turn trimmer potentiometers to our design. A simple solution is to manufacture the appropriate PCB board (We provide multiple options on the [GitHub repository](https://github.com/BadenLab/LED-Zappelin/tree/master/PCB/Potentiometer%20Mounts)).

<p align="justify">Otherwise, one can make its own little PCB by using a solderable board.
Each potentiometer connects its ClockWise (pin 3) to the LED (+) stimulator JST pin; and its Base (pin 2) to the LED (+) leg. The LED (-) stimulator JST pin connects the LED (-) leg directly.</p>

***

<p align="center"><h4 align="left">4 – Printing the Stimulator box</h4></p>

[STL files](https://github.com/BadenLab/LED-Zappelin/tree/master/3D%20Designs/Stimulator/STL%20Files) can be found on the GitHub repository and print directly if the user wishes to go for the default design (4 stimulation LEDs + 4 proxy LEDs) and [BoM](https://github.com/BadenLab/LED-Zappelin/blob/master/Bills%20of%20Materials/BOM%20-%20Stimulator.ods).

However, [SCAD files](https://github.com/BadenLab/LED-Zappelin/blob/master/3D%20Designs/Stimulator/MultiChromatic%20Stimulator%20v2.1.scad) are also available and easily adjustable for personalised design.

We used [OpenSCAD](www.openscad.com) to design the stimulator box. The tolerance of the printer can be adjusted in the “USER Parameters” section of the script (tol =0.1; by default, this value is used for Prusa MK3 and Ultimaker 2). Each component can be displayed/design individually in the “Switches” section. Variables such as LED number (4 by default) and the potentiometer board dimensions can be adjusted in the “Component Parameters” section.



<h5 align="justify">a) Rendering of the stimulator box 3D files set here by default for 4 LED channels and 4 proxy LEDs. b) Rendering of the fully mounted stimulator with all PCBs and components tightly fitting their respective space. </h5>

<p align="justify">The PCB is screwed to the “Bottom” part of the box by using M3 screws and nuts. The potentiometer board adjusts itself with the “Back” part of the box, and the trimmers should adapt to their respective holes exactly.
All part should fit tightly together and are maintained together by 4 M3*50mm socket screws. </p>

***

<p align="center"><h4 align="left">5 – Adjusting the proxy LED</h4></p>
<p align="justify">The proxy LED are markers for the experimenter to have a ready visualisation of the stimulus being displayed under the objective. If this option is selected, 3mm LEDs are to be mounted at the back of the LED holder using 3mm LED mounts.

<p align="justify">Finally, any translucid material could be placed in the LED holder slot in order to diffuse the proxy LED light (In our example, we used a piece of thin Teflon)</p>

***

<p align="center"><h4 align="left">6 – Mounting the stimulating LEDs</h4></p>
<p align="justify">Each stimulating LED must be connected to its respective channel, taking note of their polarity (long LED leg should be connected to the positive pin).

<p align="justify">For our visual stimulation setup, we combined all LED light sources into one beam which is projected through the objective to our model retina. We therefore constructed an optical cage system using a mixture of Thorlabs parts and 3D-printed objects to hold all filters and dichroic mirrors.

<p align="justify">For the optogenetics experiment we 3D-designed arenas where the sample sits, surrounded by  four LEDs. </p>


<h5 align="justify">a) SCAD files for adapting 3mm LEDs and dichroic mirrors to standard 30mm optomechanical system. b) Rendering of the LED illumination system for the visual experiment. c) For optogenetics experiment, we designed a mounting platform that holds four 3mm LEDs and can fit a RC-40HP chamber (SmartEphys, Warner Instrument).  d) Same as c) but designed to fit a small petri dish (ø 35mm) lid. </h5>

***

<p align="center"><h4 align="left">7 – Connecting the stimulator to LEDs, the microscope’s DAQ and a computer</h4></p>
<p align="justify">The stimulator can be externally powered anywhere between 5-30V via the power port. Since the TLC5947 is constant current LED driver, the voltage selection is not critical, however it should be slightly higher than the LED forward voltage (cf. LED driver datasheet). If desired, multiple LEDs can be connected to the same channel, however in this case the voltage supply must be adjusted accordingly (cf. LED driver datasheet).

<p align="justify">For the standard line-synched stimulator version with an ESP32, a line-synched 5V TTL blanking signal BNC must be fed into the stimulator from the microscope’s DAQ (if the TTL is different from 5V, this can still be accepted provided the associated resistor is changed accordingly – see soldering paragraph). Note: Since for the default ESP32 version the blanking signal is used as the external clock, the stimulator will not execute any stimuli without it. If such line-synching is not required, consult the “simple” non-synchronised version using the Arduino Nano.

<p align="justify">If required, connect the output trigger channel to the microscope’s DAQ. This signal generated by the stimulator by default sends a 3.3V pulse (if ESP32 is used, 5V for Arduino Nano) once at the start of the stimulus and then again every 1,000 ms (1 Hz exactly). The trigger signal can for example be used to time-align acquired imaging data with the stimulus in postprocessing.

<p align="justify">Finally, the board is connected to a computer via USB (micro USB for ESP32, mini USB for Arduino Nano). </p>



***

## Programming the ESP32

1-	Download and install [Arduino environment](www.arduino.org) on the computer.

2-	To use the ESP32, a couple of steps are necessary
Install the latest SiLabs [CP2104 driver](https://www.silabs.com/products/development-tools/software/usb-to-uart-bridge-vcp-drivers).
Follow the installation instructions from the [Espressif repository](https://github.com/espressif/arduino-esp32/blob/master/docs/arduino-ide/boards_manager.md).

3-	Install the TLC5947 library:	Start Arduino and from the “Sketch” tab, select “Include Library” and open “ Manage Libraries”.	From the search bar enter “TLC5947”. Select and Install the library

4-	Close Arduino and open the Multi-Chromatic-Stimulator arduino file from the [Arduino Code folder](https://github.com/BadenLab/LED-Zappelin/tree/master/Arduino%20code/2-Photon_Mutli_Chromatic_Stimulator).

<p align="justify">5-	From the “Tools” tab: Select from “Boards” the “Adafruit ESP32 Feather”.	From “Upload Speed”, select 921600.	From “Flash Frequency”, select 80Hz. From “Port”, select the computer port to which the ESP is connected (if doubt, unplug, replug and observe the choices differences). If the ESP is not recognised, check the driver installation (2), then check the micro USB cable. </p>

6-	Compile and Upload the code by clicking on the arrow button on the top left.

7-	The stimulator is ready to be used.

***

## Operating the Stimulator
<p align="center"><h4 align="left">The code is organised in five distinct part:</h4></p>

  <h4>Stimulus Parameters</h4>

<p align="justify">The code is designed to iteratively loop a pre-programmed stimulus sequence after an initial one-off optional preadaptation period

<p align="justify">- The number of loops is determined by *nLoops*. The stimulus will stop after finishing the nth  loop.

<p align="justify">–	IMPORTANT,  the number of entries within the arrays must be the same and manually entered in *nArrayEntries* (including the pre-adaptation at position 1, see below).

<p align="justify">–	The *Scan_Logic* parameter corresponds to the x-mirror scan rate in ms (i.e. = 1.0 if line speed is 1 ms per line). This value must be changed if a different scan logic is used. This value defines the tempo of the entire stimulus (Each time a blanking signal is counted, the code advances by an internal time-counter of Scan_Logic in milliseconds.)

<p align="justify">–	The *array_LED#* arrays correspond to the stimulus sequence for each LED number. Here the number of arrays must be adjusted to the number of stimulating LEDs. All array positions will be read in synchrony, based on the timing array detailed below. IMPORTANT: The first entry is not part of the to-be-looped stimulus sequence, but instead defines the LED’s brightness for the preadaptation period. Note also that the first trigger output will start with the second entry (= the first entry of the stimulation sequence). The value entered at each position is the light intensity where 0 corresponds to no light and 100 to maximal light intensity. The value entered must range between 0 and 100.

<p align="justify">–	The *array_Time* array corresponds to the duration of each entry in ms; the first entry being the pre-adaptation that will only be played at the start of the stimulus, the sequence will then loop starting at the second position. </p>



For example, if …

nLoops = 3;

nArrayEntries = 3;

Scan_Logic = 1.0;

Array_LED1 = {50,100,0};

Array_LED2 = {50,0,100};

Array_Time = {5000,1000,1000};

… the resultant stimulus will start with 5 seconds of both LEDs being set to 50% intensity (preadaptation) and will thereafter switch back and forth every 1 second between 100% and 0% power for the two LEDs in antiphase, for 3 repetitions.



***

  <h4>Microcontroller Board Selection</h4>

This is where the user defines if he is using an ESP32 or an Arduino Nano

***

  <h4>Internal Definitions</h4>

This is the main definition part of the code which can be modified to:

-	Add more LEDs than the 4 main and 4 proxy defined by default. (Global variables, the LED pins correspond to the pin number on the TLC5947).

-	Adjust the Trigger duration (25 ms by default). This value corresponds to the amount of time the trigger marker will remain on in order to be detected by i.e. a DAQ.

-	Adjust the Trigger interval (1000 ms by default). Value between two successive triggers.

***

  <h4>Internal Methods</h4>

This is the main core of the code and should not be structurally changed (apart from adding more LEDs, as required).

***

  <h4>Main Loop</h4>

This is where the stimuli controls are defined. By default, when compile window is open (magnifying glass on the top right corner) and the baud rate at the bottom right of the window has be changed to 115200, a manual command will trigger a stimulus:

By default:

This is where the serial user controls are defined. By default, when the serial monitor is open (magnifying glass on the top right corner in the Arduino IDE) and the baud rate at the bottom right of the window has be changed to 115,200, a manual command followed by pressing “enter” will trigger a stimulus:
      By default:

-	When *a* is entered in the serial monitor, the stimulator will play the sequence with intensity scaled relative to the predefine “max1_LED#” powers (see below)

-	When *b* is entered, the same stimulus sequence will be played, but this time at the intensities defined by “max2_LED#” powers (see below)

-	If *0* is entered during a stimulus sequence, all LEDs will be turned off and all loop countered will be reset.

-	Further commands can easily be programmed by the user from the “Main Loop” part of the Arduino code.

It is important to note that the stimulation will only be played if a blanking signal is sent to the board.

Important to note, obviously the stimulation will only be played if a blanking signal is sent to the board.

***

## Calibrating the Stimulator

<p align="justify">Stimulating LEDs can be approximately brought into a desired intensity regime by adding a serial resistor to limit the current they receive (c.f. 5.2). They can also be further calibrated within the code:

<p align="justify">The TLC5947 is a 12-bit PWM grayscale driver, meaning that it offers up to 4,096 grey levels to adjust each LED power.

<p align="justify">On the Arduino code there is a second tab called “LED_values” which hard-codes the maximum power an LED can get. Those values range from 0 (no current) to 4095 (max current, 15 mA by default with potentiometer tuned all the way down).

<p align="justify">On the default script we defined two distinct max values (max1 & max2) that can be called individually. The purpose here is to have the opportunity to use the same stimulus sequence at two different regimes of light intensities. More can be added manually by the user. </p>



<p align="justify">For the calibration, we suggest setting the max_LED# value to 4095 (full power) and use successively a spectrometer and a powermeter to adjust the LED brightness by finely turning the trimmer potentiometer at the back of the stimulator.

<p align="justify">As the LED output is linear relative to the values entered here (Fig. 3), any max_LED# value will be proportional to the LED power set up for the 4095 value. The LED value (0-100%) entered in the stimulus sequence is linearly mapped to 0-max_LED#.</p>

We also provide a calibration script in the form of an [iPyhton jupyter notebook](https://github.com/BadenLab/LED-Zappelin/blob/master/Instruction%20Manual/Stimulator%20Calibration/Stimulator_Calibration.ipynb). This script was designed to calibarte a 4 LEDs system for experiment on the zebrafish retina.

### Visual Stimulator Calibration

For the visual stimulator, we used the [ThorLabs Compact CCD Spectrometer](https://www.thorlabs.com/newgrouppage9.cfm?objectgroup_ID=3482) CCS200/M in combination with the [ThorLabs OSA software](https://www.thorlabs.com/software_pages/ViewSoftwarePage.cfm?Code=OSA).
We placed the spectrometer fiber patch cable at the sample position and played the calibration code on the stimulator. This calibration sequence plays each LED individually from 0 to 100% for 1 second and loops 5 times. This stimulus sequence is quite tedious so we encourage users to adapt it to their needs.
Recordings were made using the inbuilt trigger mode of the spectrometer (connected to the stimulator trigger output). We used an integration time of 1 second and applied the inbuilt spectrum correction in the OSA software. Data was extracted as .csv files and analysed using our [iPython analysis script](https://github.com/BadenLab/LED-Zappelin/blob/master/Instruction%20Manual/Stimulator%20Calibration/Stimulator_Calibration.ipynb).



For analysis purposes, we designed an [iPython notebook](https://jupyter.readthedocs.io/en/latest/install.html).
In this script, one has to first modify the global parameters:
  - Opsin maximum absorbance: *PeakWavelength* This array contains the peak asorbance for each opsin considered. For the zebrafish, we use the value defined by [Allison et al, 2004 - Visual pigment composition in Zebrafish](https://github.com/BadenLab/LED-Zappelin/blob/master/References/Allison%202004%20-%20Visual%20pigment%20composition%20in%20zebrafish.pdf)
  - Number of LEDs to be considered
  - Figure parameters: Figure sizes, spectra range to considered, etc.

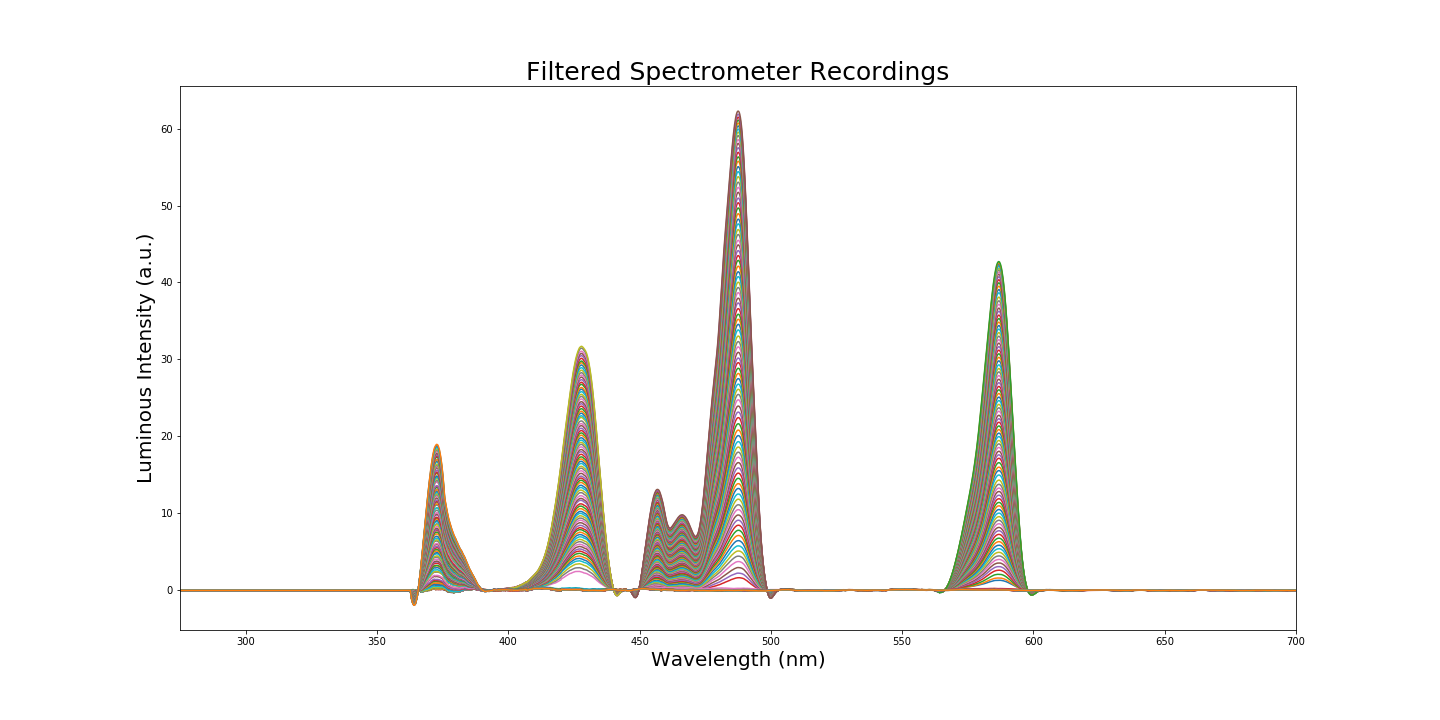
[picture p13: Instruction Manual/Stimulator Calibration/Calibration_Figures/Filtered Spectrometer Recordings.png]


.

.

The script then run a couple of slides to extract and smooth (Savitzky–Golay filter) the recording data.

From this recording, the peak wavelength of each LED is extracted and assigned to the *Peaks[ ]* array.

| | Red LED  |  Green LED |  Blue LED  | UV LED |
| ---|:---:|:---:|:---:|:---:|
| Peak Wavelength (nm)| 586.9 | 487.5 | 427.9 | 372.8 |

Depending on the LEDs used or on the extra resistors that a user might want to connect in series to substantially tune down the LEDs, a powermeter shall be used to bring the LEDs to their desired max values. Here we suggest to set the potentiometers at mid-range and replace the spectrometer sensor by the powermeter's. In our case, we used a [ThorLabs Digital Handheld Optical Power](https://www.thorlabs.de/newgrouppage9.cfm?objectgroup_id=3341) coupled with a [ThorLabs Photodiode Power Sensor S130VC](https://www.thorlabs.de/thorproduct.cfm?partnumber=S130VC), 200 - 1100 nm, 50 mW. Each LED is then successively brought to their desired maximum power (here 40nW) and the powermeter configured to the LED peak wavelengths (λmax). Once this value has been reached, the *max_LED* value in the LED Values part of the Arduino code has to be decreased until a change is oberved. The max_LED value is then hard-coded and fine tuning can be achieved with the potentiometers.
At this stage, one might retake measurements with the spectrometer with this new power (in our case equalised amongst LEDs), and rerun the first part of this script to obtain more precise curves.

<p align="justify">To establish the LEDs performance we then plotted their normalised intensities (LED relative brightness) against the PWM (*array_LED#*) used in the Arduino code to drive them. A Linear fit along with the Sum of Square Error (SSE), demonstrates that the TLC5947 LED driver controls the LED in an optimal linear manner.</p>

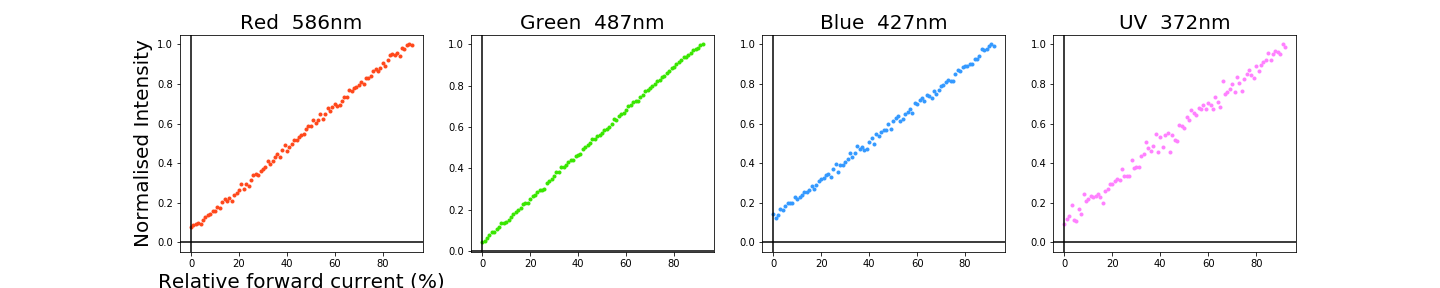
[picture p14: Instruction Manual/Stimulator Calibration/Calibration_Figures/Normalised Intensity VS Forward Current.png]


***

We then used the absorbance spectrum fitting template for visual pigment defined by [Govardoskii et al, 2000 - In Search of Visual Pigment Template](https://github.com/BadenLab/LED-Zappelin/blob/master/References/Govardovskii%202000%20-%20In%20search%20of%20the%20visual%20pigment%20template.pdf). Using the Opsin maximal absorbance defined earlier, this nomogram template describes the predicted shape of the absorbance spectra of all visual pigment. Here we obtained the following specra for the zebrafish cone photoreceptors that we plotted along the human visible spectrum as comparison.

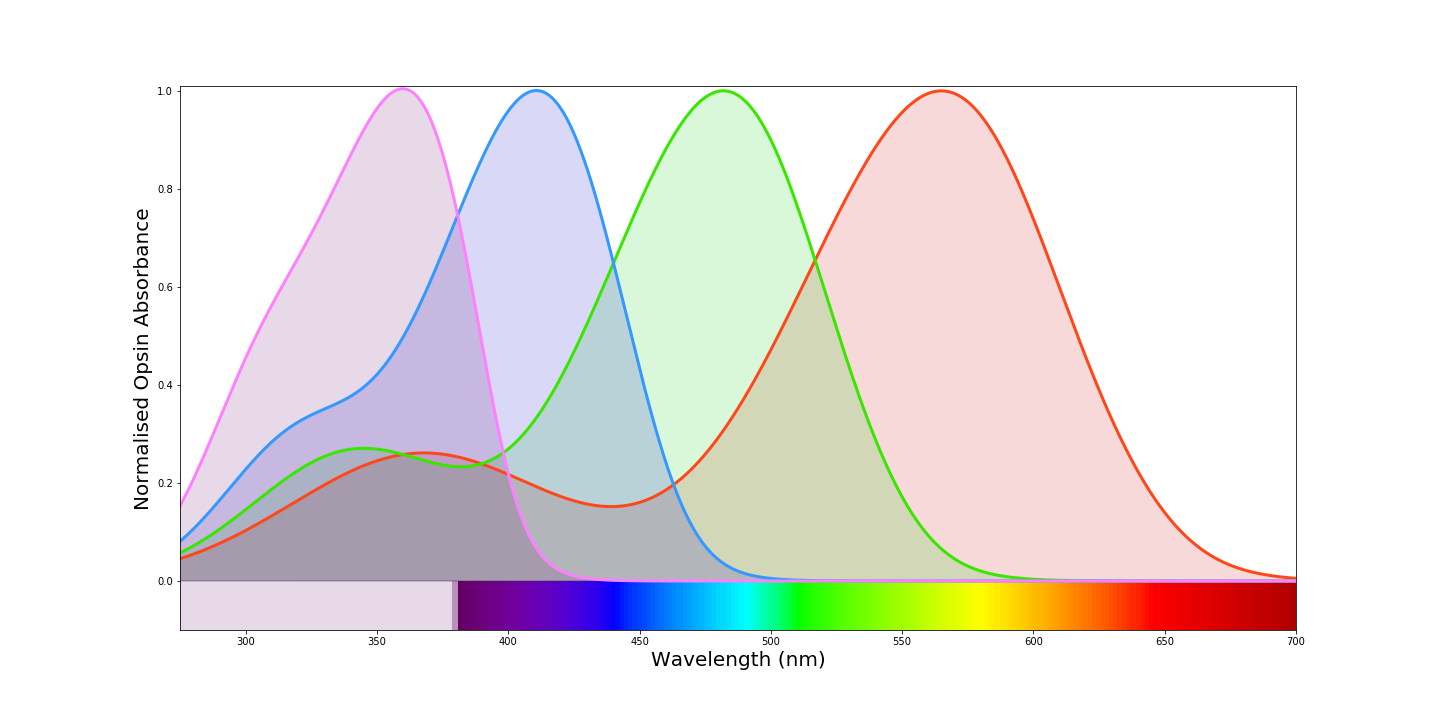
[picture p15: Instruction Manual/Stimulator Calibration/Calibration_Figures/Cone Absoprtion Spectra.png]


***

<p align="justify">Using the same display we plotted the LEDs spectra that we obtained from the spectrometer recordings.

<p align="justify">Then, we plotted the LED spectra along the cone opsin absorbance, and each LED’s spectral cross-section with respective target conein solid colours. Grey boxes indicate the positions of the two PMT detector bands. The Red-LED’s long-wavelength emission spectrum was chosen to limit spectral overlap with the red-fluorescence detection channel. Any loss in excitation efficiency of the red opsin was compensated for by increasing this LED’s power accordingly. </p>

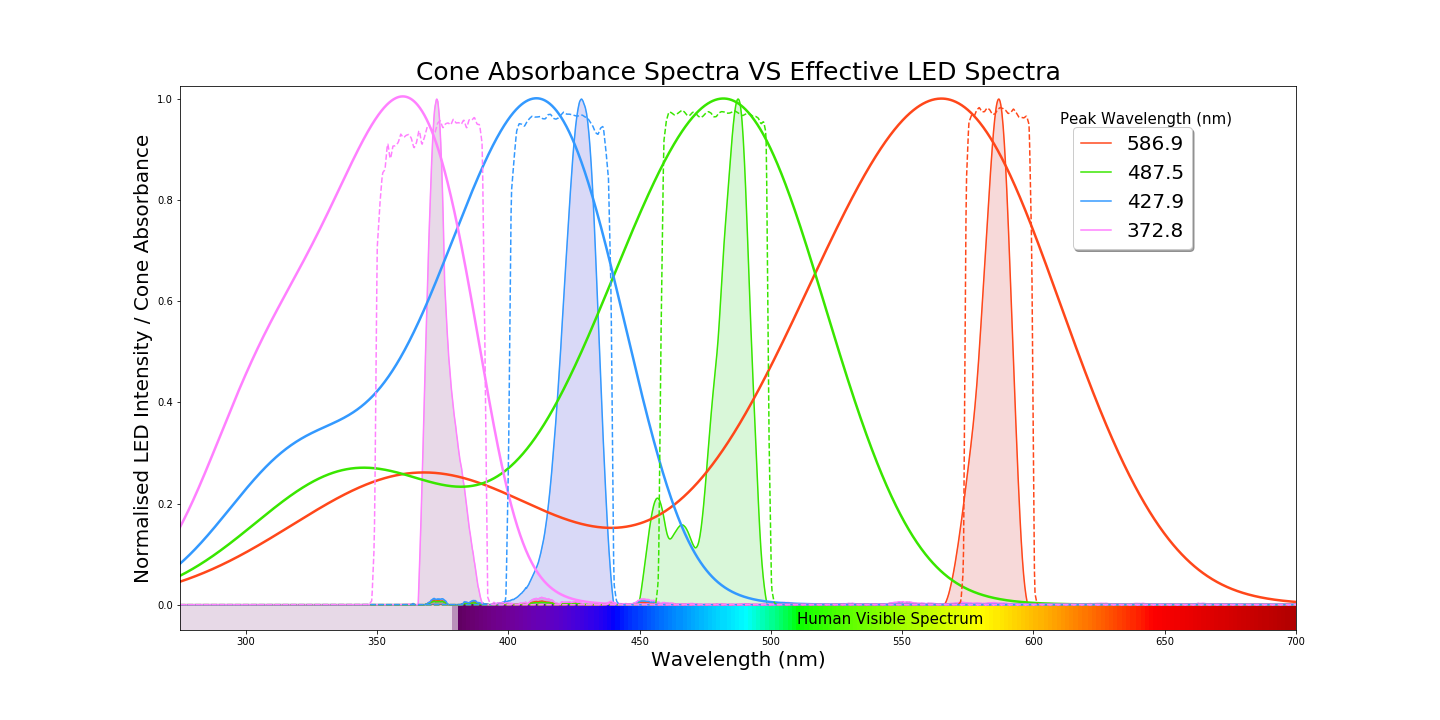
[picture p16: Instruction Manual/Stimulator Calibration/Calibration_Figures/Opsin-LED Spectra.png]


***

With the previous spectra, we estimate the relative co-excitation of photoreceptors by the LEDs:
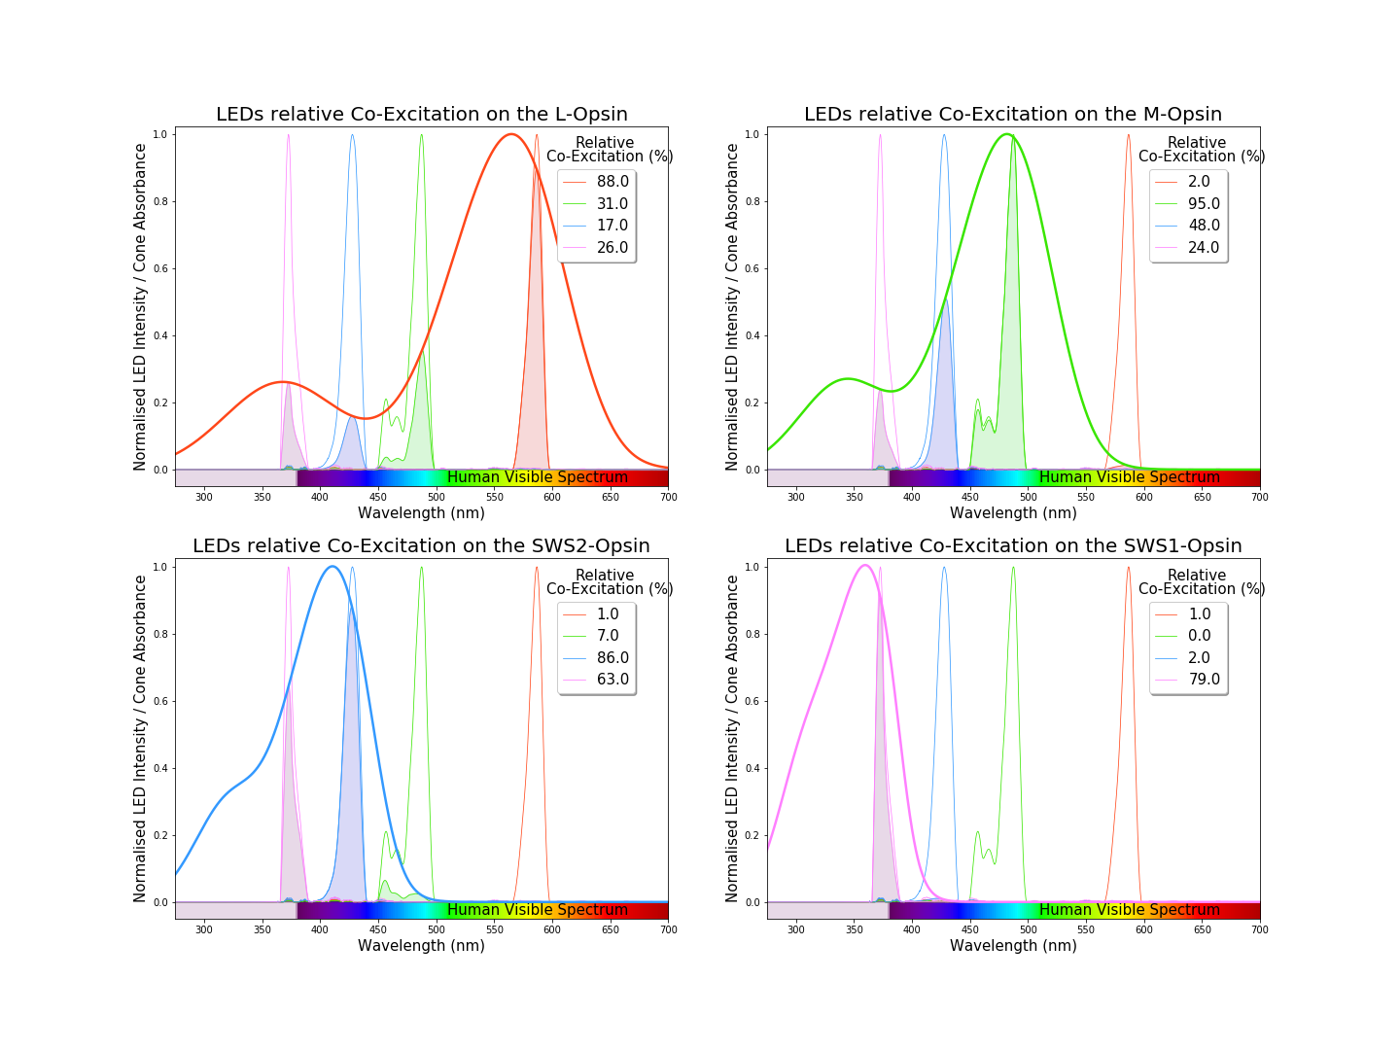
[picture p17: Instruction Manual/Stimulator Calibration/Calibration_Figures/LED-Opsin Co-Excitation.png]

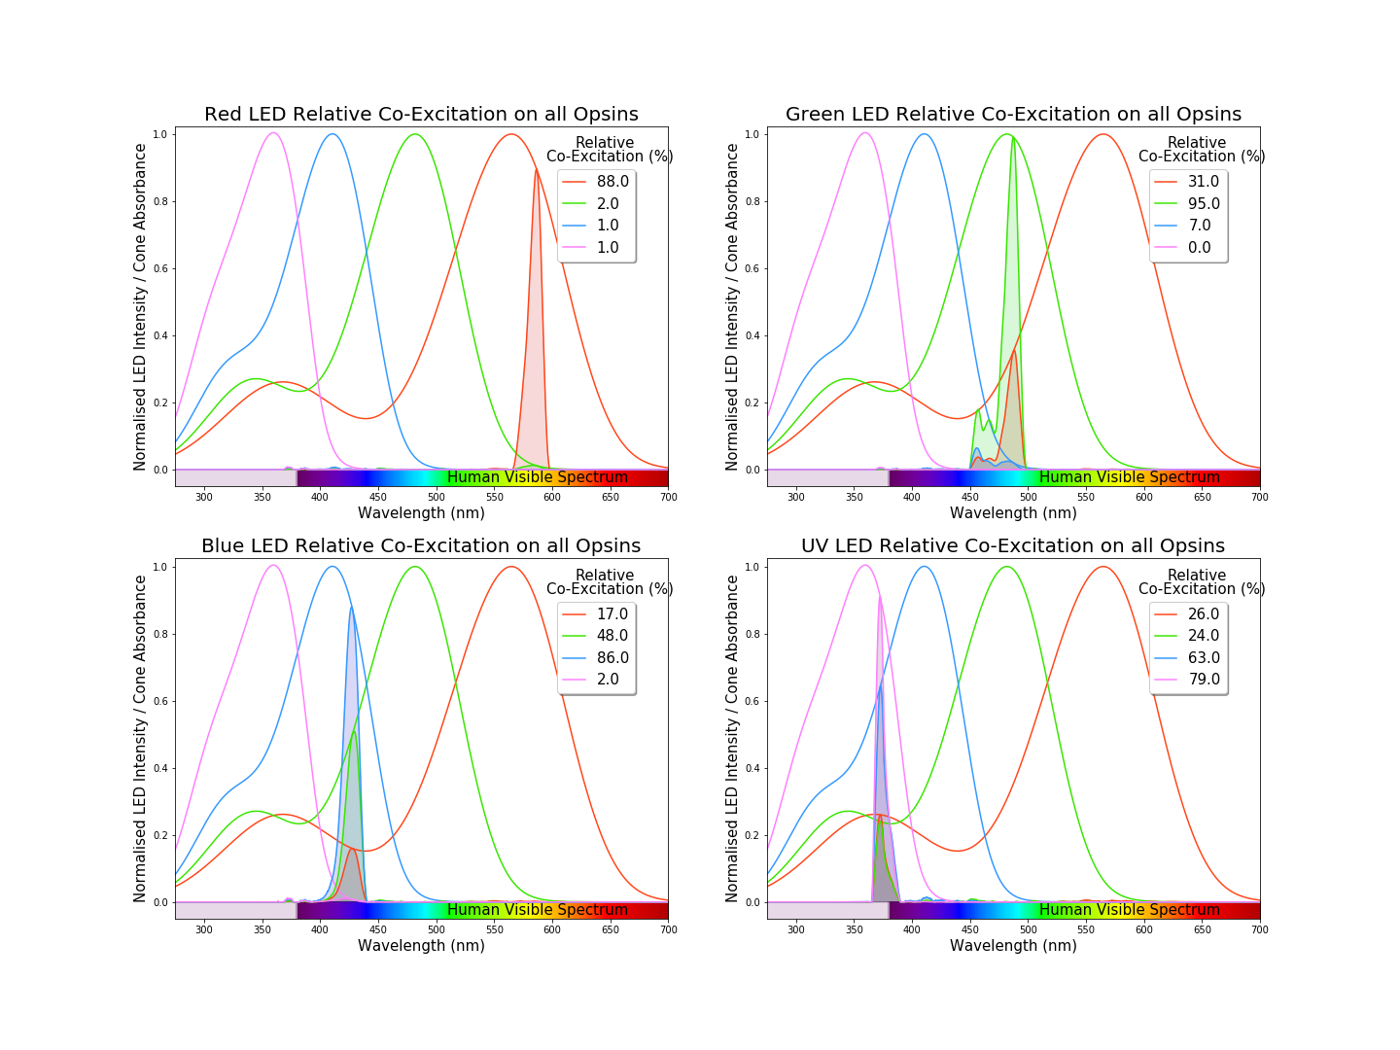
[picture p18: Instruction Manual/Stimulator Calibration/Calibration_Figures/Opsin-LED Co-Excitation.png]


***

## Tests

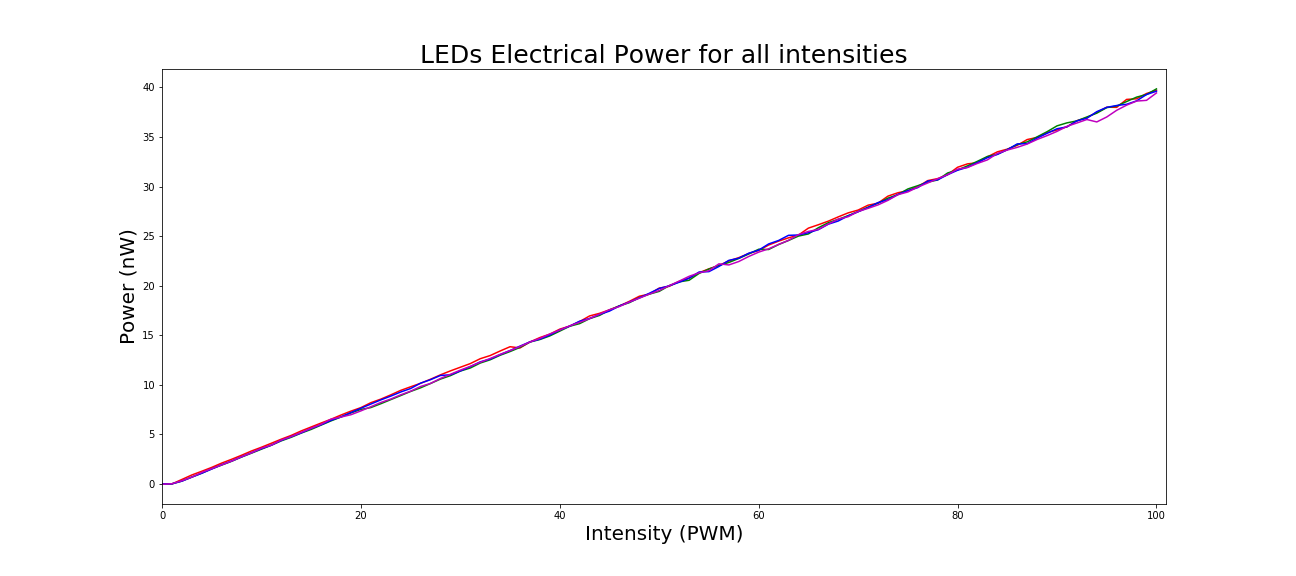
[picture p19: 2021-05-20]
Instruction Manual/Stimulator Calibration/Calibration_Figures/Powermeter Recordings.png

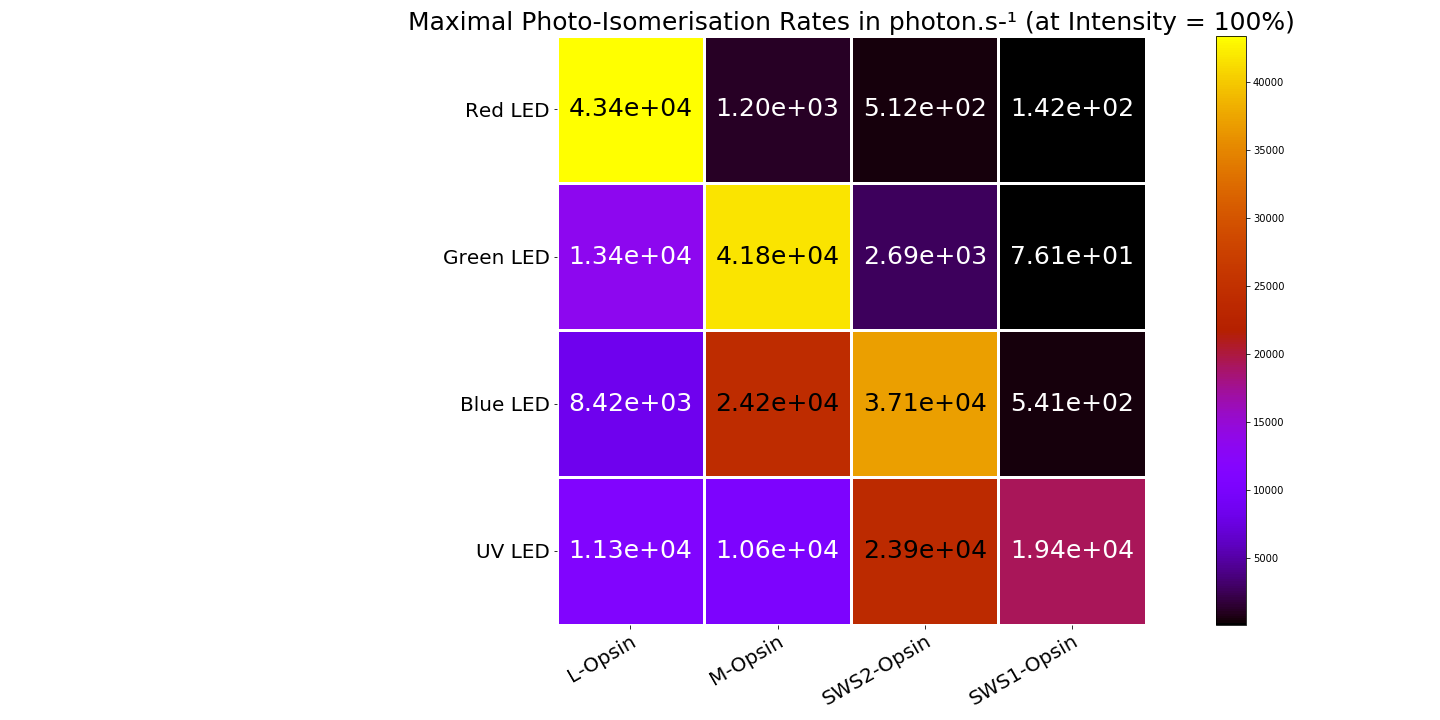
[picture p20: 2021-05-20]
Instruction Manual/Stimulator Calibration/Calibration_Figures/Photo-Isomerisation Rates Matrix.png

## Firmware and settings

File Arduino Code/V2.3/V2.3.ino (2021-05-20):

#include "Stimuli_Functions.h" 

    

/* -----------------------------------------------------------------------------------
                                 Internal methods
 ------------------------------------------------------------------------------------*/

void setup(){

// Initialise the serial communication with PC
  Serial.begin(BaudRate);

// Initialise the Adafruit TLC driver 
  tlc.begin();
  tlc.write();  

// Set pins

}

/* ----------------------------------------------------------------------------------*/
/* -------------------------------- Turn all LED off --------------------------------*/



/* ----------------------------------------------------------------------------------*/
/* ------------------------------ Play Stimulus Array -------------------------------*/


/* ----------------------------------------------------------------------------------*/
/* ----------------------------------- Main Loop ------------------------------------*/

void loop(){

        
// Check if command received from PC
  if(Serial.available()) {
    sCmd = Serial.read();

// Execute command
    switch (sCmd) {

      case '0':
        // All LEDs off
        Off();                                        
      break;

      case '+':
        // All LEDs on
        On();                                       
      break;

      case 'r':
        // All Red LEDs on
        Red();                                        
      break;

      case 'g':
        // All Green LEDs on
        Green();                                        
      break;

      case 'b':
        // All Blue LEDs ofn
        Blue();                                        
      break;

      case 'u':
        // All UV LEDs on
        UV();                                      
      break;

      case 'c':
        Red();
        delay(1000);
        Green();
        delay(1000);
       Blue();
        delay(1000);
       Off();
      break;

      case 'a':
        Colours();                                      
      break;

      case 't':
        Try();                                      
      break;

      case 'o':
        OKR();                                      
      break;
    }
  } 
}

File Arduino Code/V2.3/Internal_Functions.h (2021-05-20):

/* Global variables */  
char           sCmd;                        // Serial monitor 
word           BaudRate      = 115200;      // Baud Rate


#include <SPI.h>                            // Include the arduino serial port interface library
#include "Adafruit_TLC5947.h"               // Include the Adafruit TLC5947 libvrary. For better result one may change the number of channel defined in the Adafruit_TLC5947.cpp library


    #define   data           18             // SPI connection, DIN connected to pin MOSI/18
    #define   clock           5             // SPI connection, CLK connected to pin SCK/5
    #define   latch          21             // SPI connection, LAT connected to pin 21
    #define   oe             25             // Optional feature to prevent LED to light up when powering up the TLC board connected to pin A1/DAC1


    Adafruit_TLC5947 tlc = Adafruit_TLC5947(4, clock, data, latch);

int            R_maxvalue       = 4095;
int            G_maxvalue       = 4095;
int            B_maxvalue       = 4095;
int            U_maxvalue       = 2047;

int            midvalue       = 2047;

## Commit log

2021-05-20 Update Arduino codes
2021-05-20 Update PCB
    [Behaviour project.kicad_pcb, Behaviour project.sch]
2021-05-20 Update 3D design
    [Camera_Holder.stl, Dish_Holder.stl, Dish_Separator.stl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]
2021-05-20 Update Instruction Manual
    [Behaviour project.kicad_pcb, Behaviour project.sch, Blue.csv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]
2021-05-20 Update BoM
    [BOM - Stimulator.csv]
